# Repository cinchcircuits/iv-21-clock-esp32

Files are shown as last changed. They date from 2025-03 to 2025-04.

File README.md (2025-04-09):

# iv-21-clock-esp32
Basic clock designed around a IV-21 FL tube

# Attributions
- This project was largely mutated from [sjm4306s project](https://hackaday.io/project/167749-tiny-iv-21-vfd-clock)
- The max6921 control code was borrowed from [DellaRaccoon](https://github.com/DellaRaccoon/vfd-control/tree/master)
- the mcp3x21 code was pulled from "Andon", I do not recall where I found it.
- As always, many thanks to [Adafruit](https://www.adafruit.com/) for all of their contributions to circuit python

# What is on the board
- A FL tube, a IV-21
- XIAO board. I am using a ESP32C3, but many micro controllers work
- mcp3x21 A2D converter for getting feedback of the drive voltage for the device 

# Design files
Find the board files [Here](eagle-files)

# Case cad files
I made a simple case for this device in Fusion 360. 
All files are avaliable [Here](case-cad)

# Code
The esp32 code can be found [here](esp32-code)

This code is still a WIP. It doesn't do more than display some numbers.

Most of the code development tims so far was just in getting the dc-2-dc circuit working correctly.

This is an image of the clock running:
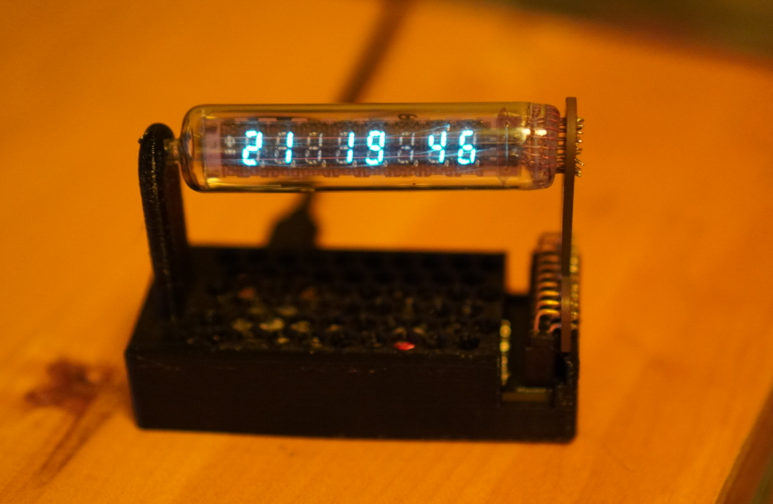
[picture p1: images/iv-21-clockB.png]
light


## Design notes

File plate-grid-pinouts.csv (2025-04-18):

IV-21-pin | Board trace | max6921 pin | max6921 signal | IV-18 pin |  | 1v-21 Plate designations
plate1 | G | 19 | out7 | 12 |  | D
plate2 | B | 18 | out8 | 10 | C |  | B
plate3 | F | 17 | out9 | 4 |  | A
plate4 | A | 6 | out16 | 3 | H |  | G
plate5 | DP | 22 | out4 | 5 |  | F
plate6 | D | 23 | out3 | 11 |  |  | E (This is the dot)
plate7 | C | 21 | out5 | 9
plate8 | E | 20 | out6 | 2
Grid1 | G1 | 7 | out15 | 15
grid2 | G2 | 25 | out1 | 22
grid3 | G3 | 9 | out13 | 16
grid4 | G4 | 24 | out2 | 21
grid5 | G5 | 8 | out14 | 17
grid6 | G6 | 26 | out0 | 20
grid7 | G7 | 10 | out12 | 19
grid8 | G8 | 11 | out11 | 18
grid9 | G9 | 12 | out10 | 14
Field 1 | F1 |  |  | 1
Field 2 | F2 |  |  | 13

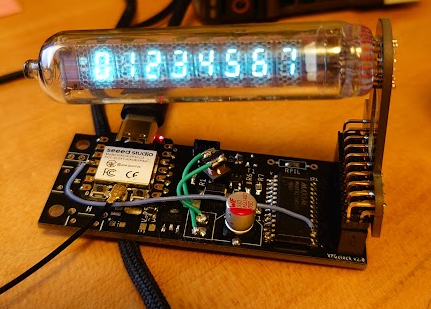
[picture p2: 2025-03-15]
images/iv-21.png

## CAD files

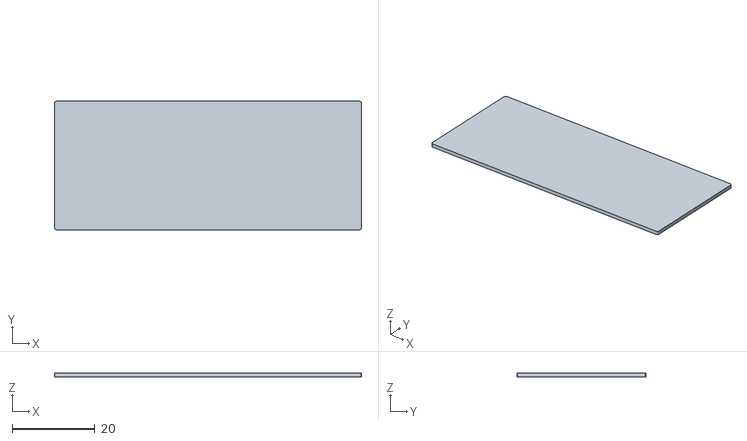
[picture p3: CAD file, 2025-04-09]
case-cad/fl-bottom.stl
74.0 x 31.0 x 1.00

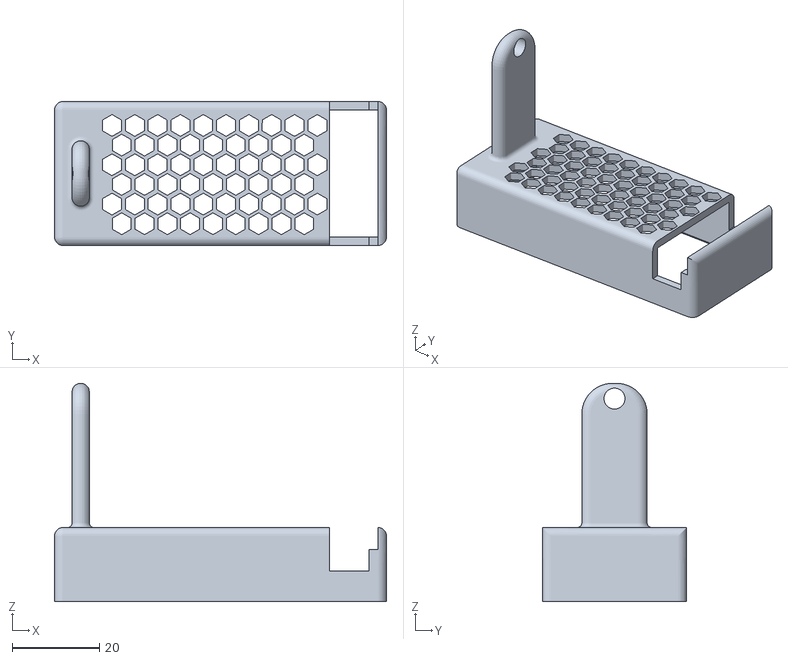
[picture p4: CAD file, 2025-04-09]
case-cad/FL-holder-1.stl
76.0 x 33.0 x 50.0

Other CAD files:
case-cad/FL-holder-1.f3d

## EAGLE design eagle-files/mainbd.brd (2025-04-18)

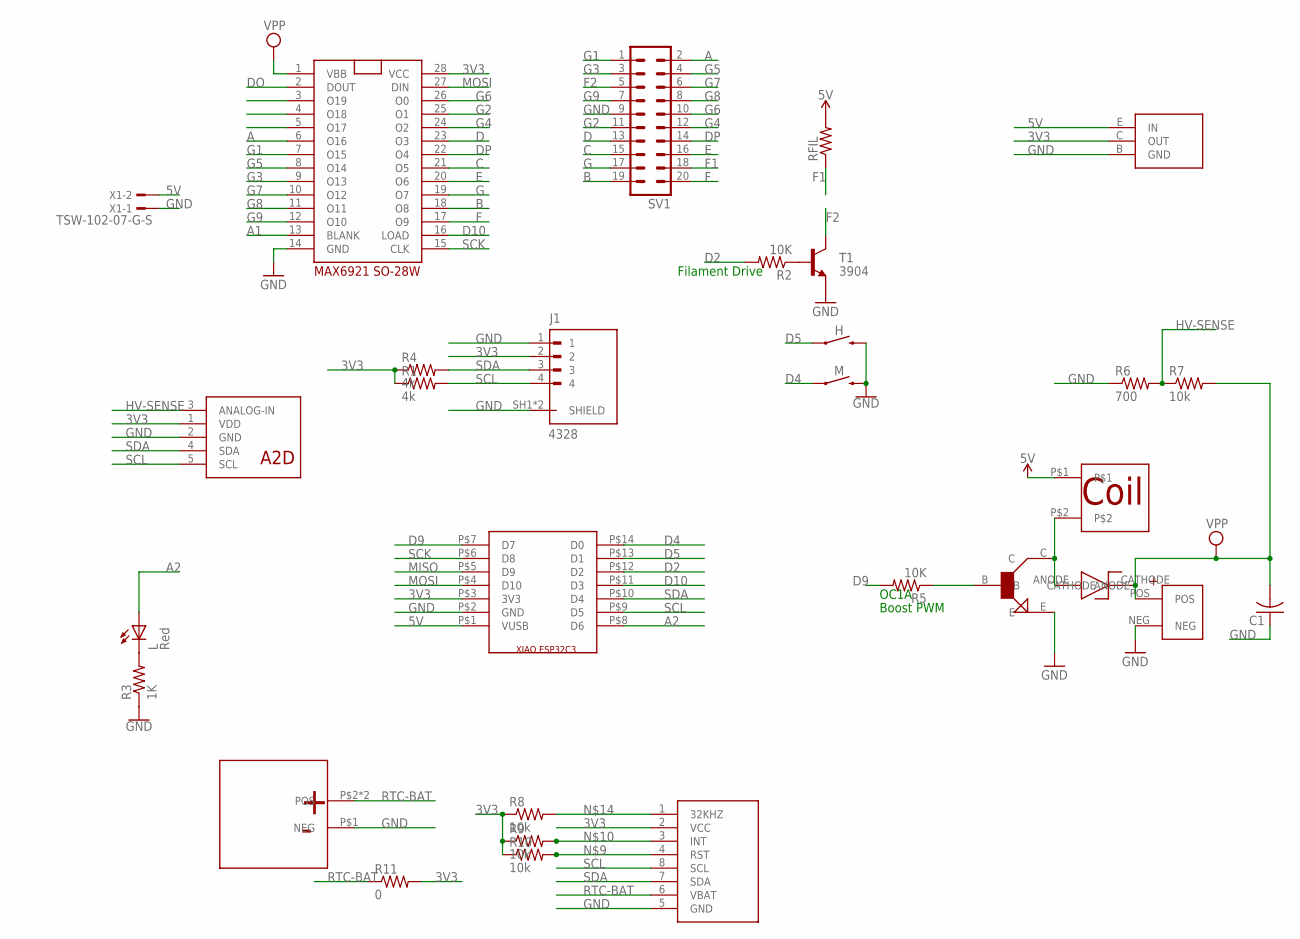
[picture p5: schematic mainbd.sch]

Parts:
3.3V-LDO: LDO-3.3V-AZ1117CR-3.3TRG1; SOT89-BCE
.: NPN-2SCR513P5; SOT89-BCE
C1: C-USC0805; C0805
H: MOMENTARY-SWITCH-SPST-PTH-RIGHT-ANGLE-KIT; TACTILE_SWITCH_PTH_RIGHT_ANGLE_KIT
J1: 4328; ADAFRUIT_4328
L: Red; CHIP-LED0805
M: MOMENTARY-SWITCH-SPST-PTH-RIGHT-ANGLE-KIT; TACTILE_SWITCH_PTH_RIGHT_ANGLE_KIT
R1, R4: 4k; R0805W
R2, R5: 10K; M0805
R3: 1K; M0805
R6: 700; R0805W
R7: 10k; R0805W
R8, R9, R10: 10k; M0805
R11: 0; M0805
RFIL: FLIPFLOP-RES; 0805-THM
SV1: MA10-2
T1: 3904; SOT23-BEC
U$1: MAX6921; SO28W
U$3: DS3231M; SOIC8
U$4: CAP-330
U$5: BATTERY-2998-COIN
U$6: INDUCTOR-453226
U$7: XIAOESP32C3
U$8: A2D-MCP3221A6T; SOT23-5
U$9: DIODE-ZENIER-CMSH1-20MLTR13; SMA-DIODE
X1: TSW-102-07-G-S; TSW-102-XX-G-S

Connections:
3V3: 3.3V-LDO.C (OUT), J1.2, R1.1, R4.1, R8.1, R9.1, R10.1, R11.2, U$1.28 (VCC), U$3.2 (VCC), U$7.P$3 (3V3), U$8.1 (VDD)
5V: 3.3V-LDO.E (IN), RFIL.2, U$6.P$1, U$7.P$1 (VUSB), X1.2
A: SV1.2, U$1.6 (O16)
A1: U$1.13 (BLANK)
A2: L.A, U$7.P$8 (D6)
B: SV1.19, U$1.18 (O8)
C: SV1.15, U$1.21 (O5)
D: SV1.13, U$1.23 (O3)
D2: R2.2, U$7.P$12 (D2)
D4: M.1, U$7.P$14 (D0)
D5: H.1, U$7.P$13 (D1)
D9: R5.2, U$7.P$7 (D7)
D10: U$1.16 (LOAD), U$7.P$11 (D3)
DO: U$1.2 (DOUT)
DP: SV1.14, U$1.22 (O4)
E: SV1.16, U$1.20 (O6)
F: SV1.20, U$1.17 (O9)
F1: RFIL.1, SV1.18
F2: SV1.5, T1.C
G: SV1.17, U$1.19 (O7)
G1: SV1.1, U$1.7 (O15)
G2: SV1.11, U$1.25 (O1)
G3: SV1.3, U$1.9 (O13)
G4: SV1.12, U$1.24 (O2)
G5: SV1.4, U$1.8 (O14)
G6: SV1.10, U$1.26 (O0)
G7: SV1.6, U$1.10 (O12)
G8: SV1.8, U$1.11 (O11)
G9: SV1.7, U$1.12 (O10)
GND: 3.3V-LDO.B (GND), ..E, C1.1, H.2, J1.1, J1.SH1 (SHIELD), J1.SH2 (SHIELD), M.2, R3.1, R6.1, SV1.9, T1.E, U$1.14 (GND), U$3.5 (GND), U$4.NEG, U$5.P$1 (NEG), U$7.P$2 (GND), U$8.2 (GND), X1.1
HV-SENSE: R6.2, R7.1, U$8.3 (ANALOG-IN)
MISO: U$7.P$5 (D9)
MOSI: U$1.27 (DIN), U$7.P$4 (D10)
unnamed: L.C, R3.2
unnamed: ..B, R5.1
unnamed: ..C, U$6.P$2, U$9.ANODE
unnamed: R10.2, U$3.4 (RST)
unnamed: R9.2, U$3.3 (INT)
unnamed: R8.2, U$3.1 (32KHZ)
unnamed: R2.1, T1.B
RTC-BAT: R11.1, U$3.6 (VBAT), U$5.P$2 (POS), U$5.P$3 (POS)
SCK: U$1.15 (CLK), U$7.P$6 (D8)
SCL: J1.4, R1.2, U$3.8 (SCL), U$7.P$9 (D5), U$8.5 (SCL)
SDA: J1.3, R4.2, U$3.7 (SDA), U$7.P$10 (D4), U$8.4 (SDA)
VPP: C1.2, R7.2, U$1.1 (VBB), U$4.POS, U$9.CATHODE

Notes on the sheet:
Filament Drive
OC1A
Boost PWM

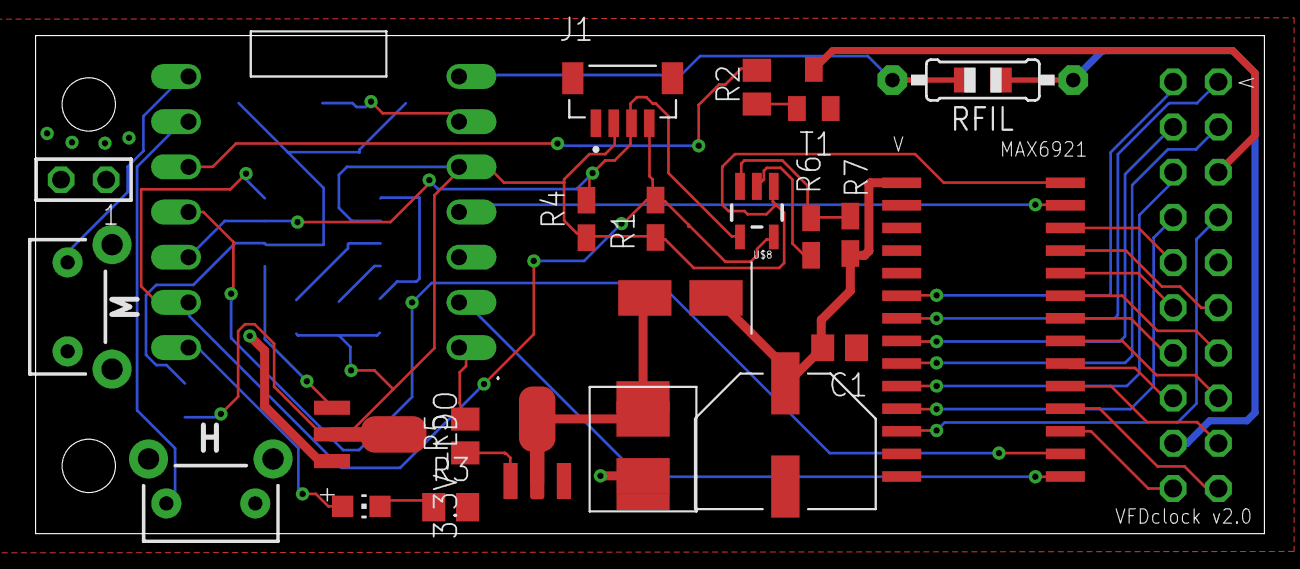
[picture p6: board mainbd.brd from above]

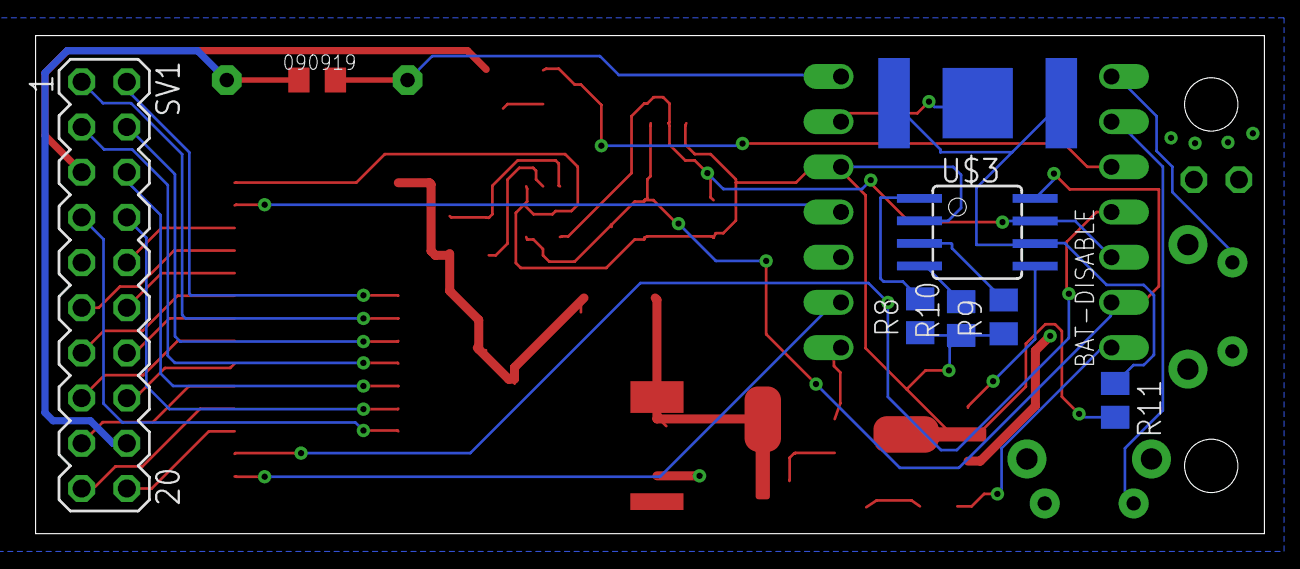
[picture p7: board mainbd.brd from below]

Board: 2 copper layers, 69.1 x 28.0 mm, 31 parts (7 on the bottom side), 42 nets.

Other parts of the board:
U$2: SJM4306_SMALL_NO_MASK

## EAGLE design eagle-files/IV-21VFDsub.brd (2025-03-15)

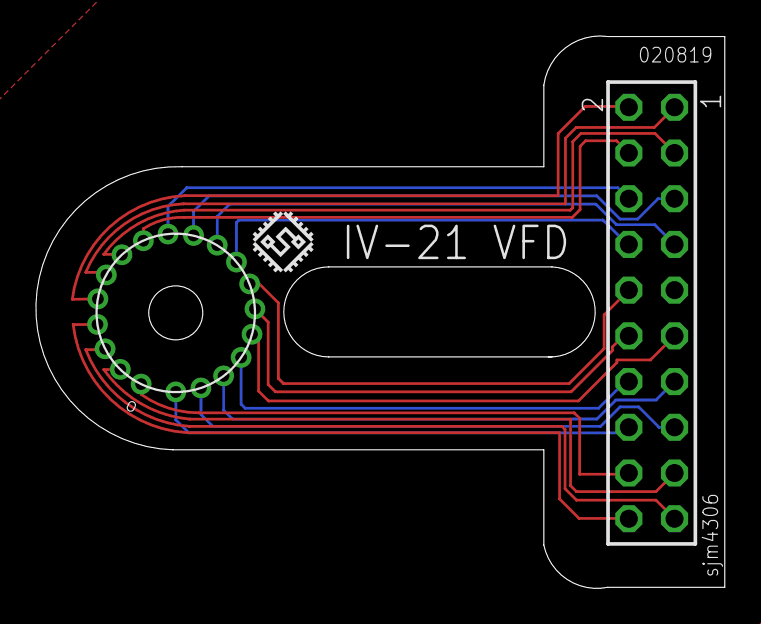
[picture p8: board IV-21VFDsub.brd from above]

Board: 2 copper layers, 38.3 x 30.7 mm, 4 parts (1 on the bottom side), 19 nets.

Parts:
U$1: IV-21VFD
U$2, U$3: SJM4306_LOGO_SMALL
X1: TSW-110-07-G-D; TSW-110-XX-G-D

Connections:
A: U$1.P$5, X1.2
B: U$1.P$3, X1.19
C: U$1.P$18, X1.15
D: U$1.P$17, X1.13
DP: U$1.P$16, X1.14
E: U$1.P$19, X1.16
F: U$1.P$4, X1.20
F1: U$1.P$1, X1.18
F2: U$1.P$10, X1.5
G: U$1.P$2, X1.17
G1: U$1.P$6, X1.1
G2: U$1.P$15, X1.11
G3: U$1.P$7, X1.3
G4: U$1.P$14, X1.12
G5: U$1.P$8, X1.4
G6: U$1.P$13, X1.10
G7: U$1.P$9, X1.6
G8: U$1.P$12, X1.8
G9: U$1.P$11, X1.7

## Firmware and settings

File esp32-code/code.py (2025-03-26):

import board
import cp_mcp3x21
import time
import pwmio
import adafruit_ntp
import socketpool
import wifi
import os
from max6921 import VFD
import digitalio
import supervisor

i2c = board.I2C()
mcp = cp_mcp3x21.MCP3021(i2c)

# Set to 1 to make daylight savings adjustments
DST = 1

# Filament transistor attached to pin 2
#fpwm = pwmio.PWMOut(board.D2, variable_frequency=True)
#fpwm.frequency = 200
#pwm.frequency = 1050
#fpwm.duty_cycle = 1000

# PWM on pin 7, duty cycle 0, 100khz
#pwm = pwmio.PWMOut(7, 0, 100000)
pwm = pwmio.PWMOut(board.D7, variable_frequency=True)
pwm.frequency = 34050
#pwm.frequency = 1050
pwm.duty_cycle = 0

# Initial startup values. Should make for a low voltage
freq = 2200
#freq = 14100
duty = 12000
vtarget = 27.0 # target voltage

# Get wifi AP credentials from a settings.toml file
wifi_ssid = os.getenv("CIRCUITPY_WIFI_SSID")
wifi_password = os.getenv("CIRCUITPY_WIFI_PASSWORD")
if wifi_ssid is None:
    print("WiFi credentials are kept in settings.toml, please add them there!")
    raise ValueError("SSID not found in environment variables")

goodwifi = 0
while goodwifi == 0:
    try:
        print("Attempting wifi connection")
        wifi.radio.connect(wifi_ssid, wifi_password)
        goodwifi = 1
    except ConnectionError:
        print("Failed to connect to WiFi with provided credentials")
        goodwifi = 0
        time.sleep(5)
    
import ipaddress
ping_ip = ipaddress.IPv4Address("10.128.128.1")  # Google.com
ping = wifi.radio.ping(ip=ping_ip)

# retry once if timed out
if ping is None:
    ping = wifi.radio.ping(ip=ping_ip)

if ping is None:
    print("Couldn't ping 'google.com' successfully")
else:
    # convert s to ms
    print(f"Pinging 'google.com' took: {ping * 1000} ms")
    
print("WiFi connection Success")
timez = os.getenv("TIMEZONE")
timezone = int(timez)

pool = socketpool.SocketPool(wifi.radio)
ntp = adafruit_ntp.NTP(pool, tz_offset=timezone, cache_seconds=3600)

print(ntp.datetime)

load = digitalio.DigitalInOut(board.D3)
load.direction = digitalio.Direction.OUTPUT
digits = [(load, 15), (load, 1), (load, 13), (load, 2), (load, 14), (load, 0), (load, 12), (load, 11),(load, 10), (load, 17), (load, 18), (load, 19)]
#digits = [(load, 19), (load, 18), (load, 17), (load, 10), (load, 11), (load, 12), (load, 0), (load, 14), (load, 2), (load, 13), (load, 1), (load, 15)]
segments = [(load, 16), (load, 8), (load, 5), (load, 3), (load, 6), (load, 9), (load, 7), (load, 4)]

vfd = VFD(digits, segments)

def get_voltage(value, ref, max_value=1024):
    # Our value will be between 0 and either 1024 or 4096, depending.
    # We'll default to the max being 1024, but that can be changed.
    value = float(value) # We want the final result to be a float anyway.
    # What we do here is take the proportion of the value to the max value
    # And multiply that by the voltage we're measuring.
    # So if we have a lipo battery that tops out at 4.2v, we'd use 4.2 as
    # the reference. If our reading is 900 out of 1024, that's 0.88 (ish),
    # multiplied by 4.2 gives us 3.7v, or a usual battery charge. If it was
    # around 780, that'd be at 3.2 volts, or worryingly dead.
    volts = (value / max_value) * ref
    return volts

#vs = 10.0
time.sleep(1)
pwm.duty_cycle = duty
pwm.frequency = freq

# start Filament F2
filament = digitalio.DigitalInOut(board.D2)
filament.direction = digitalio.Direction.OUTPUT
filament.value = True

# Used to reduce output of voltage updates
v_updates = 10

# Checks the VFS voltage. Adjust if nessary
def check_vfd(duty, updates):
    pwm.duty_cycle = duty
    #pwm.duty_cycle = 34000
    #pwm.duty_cycle = 40000
    lvoltage = get_voltage(mcp.value, 3.29, 1024)
    voltage = lvoltage * 17.75
    if voltage < vtarget:
        duty = duty+10
    else:
        duty = duty-10
    if duty > 63900:
        duty = 50
    if updates == 1:    
        print(voltage)
        print(duty)
    return duty

now = ntp.datetime

while True:
    now_ms = supervisor.ticks_ms()
    div_ms = now_ms / 10
    div_sec = div_ms / 10
    if ( div_ms % 4 ) == 0:
        if v_updates >= 10:
            rduty = check_vfd(duty, 1)
            v_updates = 0
        else:
            rduty = check_vfd(duty, 0)
            v_updates = v_updates + 1
        duty = rduty
    if ( div_sec % 10 ) == 0:
        now = ntp.datetime
        #print(ntp.datetime)
        #print(now.tm_sec)
    if ( div_ms % 1 ) == 0:
        hour = now.tm_hour
        minn = now.tm_min
        sec = now.tm_sec
        # alter time for DST
        if DST == 1:
            if now.tm_yday > 67 and now.tm_yday < 307:
                if hour == 23:
                    hour = 0
                else:
                    hour = hour + 1
        if hour < 10:
            hh = (" %d" % (hour))
        else:
            hh = ("%d" % (hour))
        if minn < 10:
            mm = (" %d" % (minn))
        else:
            mm = ("%d" % (minn))
        if sec < 10:
            ss = (" %d" % (sec))
        else:
            ss = ("%d" % (sec))
        hr = ("%s %s %s   " % ( hh, mm, ss ))
        reversed_hr = ("%c%c%c%c%c%c%c%c" % (hr[7], hr[6], hr[5], hr[4], hr[3], hr[2], hr[1], hr[0]))
        vfd.print(reversed_hr)
        #print(hr)
        #print(reversed_hr) // Standard python reversing methods completly failed here. 
        #vfd.print("76-43219")
        #vfd.print("8888")
        vfd.draw()

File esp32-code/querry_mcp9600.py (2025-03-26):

import time
import board
import busio
import adafruit_mcp9600


i2c = busio.I2C(board.SCL, board.SDA, frequency=100000)
mcp = adafruit_mcp9600.MCP9600(i2c, 0x67)
mcpb = adafruit_mcp9600.MCP9600(i2c, 0x60)


while True:
    print((mcp.ambient_temperature, mcp.temperature, mcp.delta_temperature))
    print((mcpb.ambient_temperature, mcpb.temperature, mcpb.delta_temperature))
    print("")
    time.sleep(1)

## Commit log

2025-03-15 Adding eagle files
    [IV-21VFDsub.brd, mainbd.brd, mainbd.sch]
2025-03-15 Adding pinout notes
    [plate-grid-pinouts.csv]
2025-03-16 Moving componets around a little bit to better accomidate xaio board
    [mainbd.brd]
2025-04-01 Fixing a few bugs, one involving ntp timeoits
    [adafruit_ntp.py, check_hv.py]
2025-04-01 etting just a zero return when the ntp update fails
    [adafruit_ntp.py]
2025-04-09 Switching to a better image of the clock
2025-04-09 Adding CAD files from the basic case
    [FL-holder-1.f3d, FL-holder-1.stl, fl-bottom.stl]
2025-04-18 Statring work on adding IV-18 support
    [iv-18.brd, iv-18.sch, mainbd.brd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]
2025-04-18 Adding cam file for production
    [iv-18.brd, mainbd.brd]
2025-04-18 final tweak to one track on iv-18 brd
    [iv-18.brd]

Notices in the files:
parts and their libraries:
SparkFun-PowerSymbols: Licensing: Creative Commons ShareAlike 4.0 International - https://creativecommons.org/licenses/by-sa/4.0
